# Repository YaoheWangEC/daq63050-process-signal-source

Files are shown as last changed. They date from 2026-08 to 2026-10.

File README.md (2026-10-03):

# DAQ63050 — 过程信号源

> Process Signal Source



---

## 简介 | Introduction

DAQ63050 是一款基于 **AT32L021** 的过程信号源，配合 12-bit DAC TPC112S1 和高精度电压基准 TPR3540 实现了一个可靠的信号源，支持直流（DC）、1 kHz 方波、1 kHz 正弦三种输出模式，可通过 [Linux CLI 风味命令](https://github.com/YaoheWangEC/linux-cli-style-command-driver-framework) 进行控制，也可通过板载按键本地操作。

DAQ63050 is a process signal source based on the **AT32L021** MCU, paired with a 12-bit DAC (TPC112S1) and a high-precision voltage reference (TPR3540). It supports three output modes — DC, 1 kHz square wave, and 1 kHz sine wave — and can be controlled via [Linux CLI-style commands](https://github.com/YaoheWangEC/linux-cli-style-command-driver-framework) or locally through on-board keys.

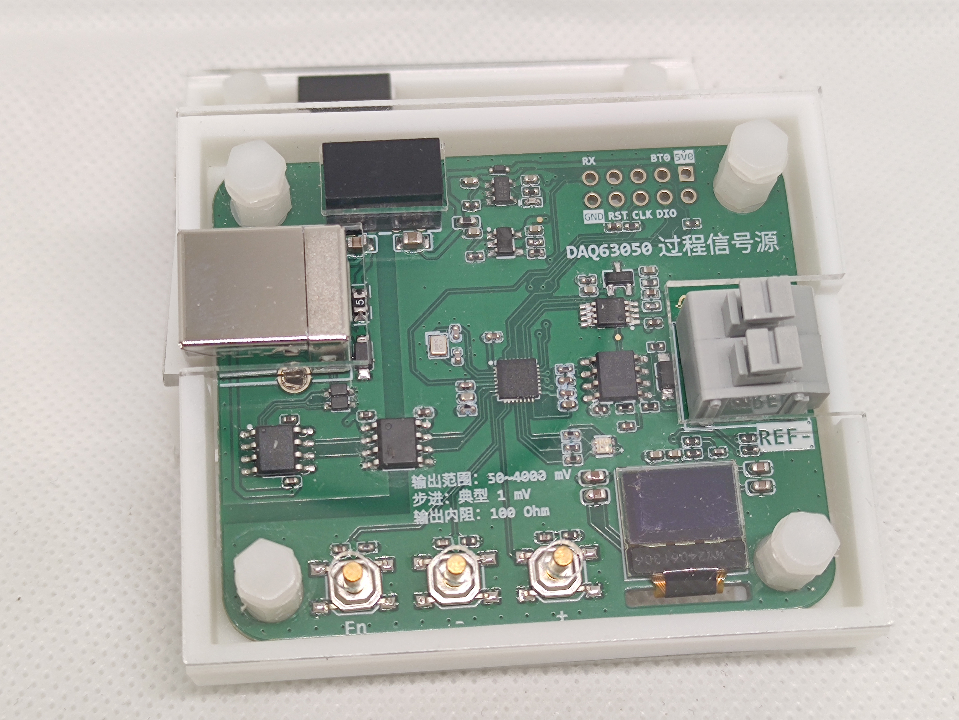
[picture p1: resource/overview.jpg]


> 视频演示：*待补充* ｜ 立创开源：*待补充*

## 主要参数 | Specifications

| 参数 | 值 | 备注 |
| --- | --- | --- |
| 供电 | 5 V 100 mA | 隔离供电 |
| 输出范围 | 0.1 ~ 4.0 V | 输出阻抗 100 Ω |
| 输出分辨率 | 典型 1 mV | VREF = 4.096 V @ 12 bit |
| 输出模式 | DC / 1 kHz 方波 / 1 kHz 正弦 | 采样率 50 kHz |
| 通信接口 | UART（CH340） | 115200 / 8N1 |

---

## 快速上手 | Getting Started

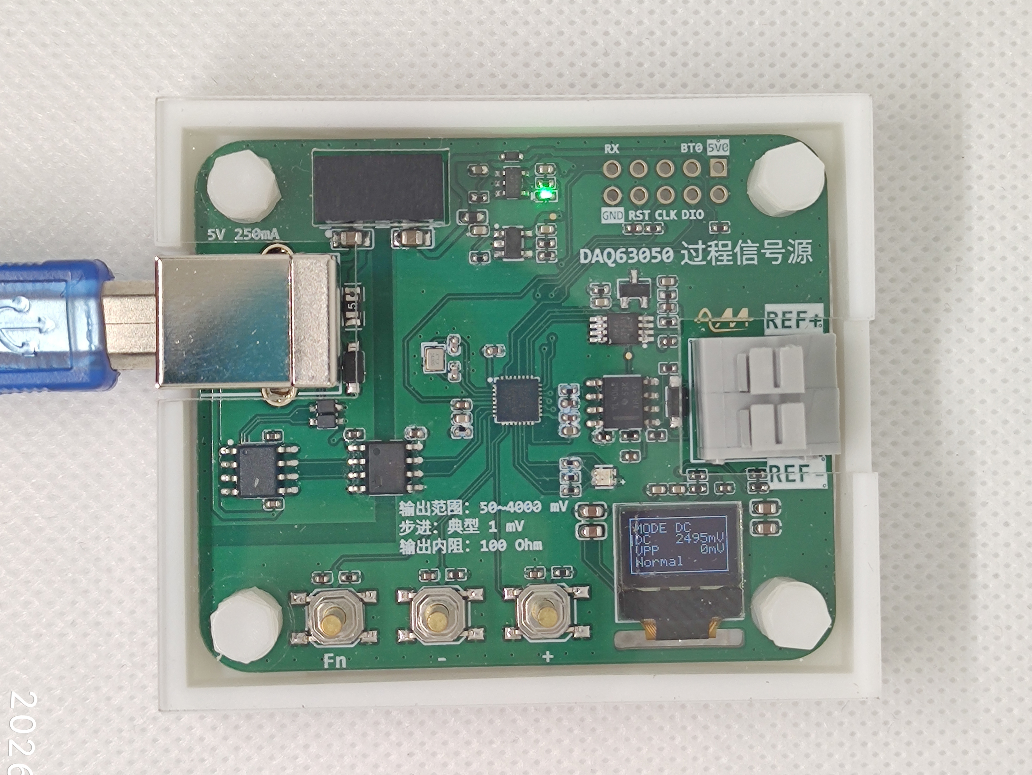
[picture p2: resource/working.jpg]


### 1. 接线 | Wiring

| 接口名 | 接口形态 | 功能 | 备注 |
| --- | --- | --- | --- |
| USB 接口 | USB Type-B | 供电 + 通信 | CH340, 115200 8N1 |
| 信号输出接口 | 弹簧接线端子 | 波形输出 | 0.1 ~ 4.0 V |

### 2. 上电 | Power On

接通电源后，OLED 显示 `Hello world!` / `DAQ63050`，随后进入输出界面。默认输出直流 2.495 V。

### 3. 输出连接 | Output Connection

将信号输出端接入负载或被测设备。输出为 0.1 ~ 4.0 V 单极性信号，请勿超出量程。

DC 模式下，固件通过 ADC 回采实际输出并与设定值比较；当偏差超过 ±30 mV 时（输出电流超过 3 mA），OLED 显示 `OVERLOAD`，提示输出因负载过重发生跌落。

### 4. 本地操作 | Local Control

| 按键 | 短按 | 长按 |
| --- | --- | --- |
| FN | 切换"选择项 / 修改值"状态 | 切换输出模式（DC → 方波 → 正弦 → DC） |
| INC | 非修改态：切换选项；修改态：+1 | 修改态：+10 |
| DEC | 非修改态：切换选项；修改态：-1 | 修改态：-10 |

可调选项为 **直流偏置（DC）** 与 **峰峰值（VPP）**，修改值同时受峰谷约束（见下）。

### 5. UART 控制 | UART Control

使用 USB Type-B 数据线连接电脑：

```
PC (USB) -> USB Type-B 线 -> DAQ63050 (CH340 -> UART)
```

串口参数：**115200 bps, 8 data bits, 1 stop bit, no parity**

上电后发送 `lscmd` 可列出所有命令。DAQ63050 采用 [Linux CLI 风格](https://github.com/YaoheWangEC/linux-cli-style-command-driver-framework) 的 ASCII 文本协议，命令以 `\r\n` 结束，响应同样以 `\r\n` 结束，一问一答。

> `offset` 与 `vpp` 命令的数值单位为 mV，与 DAC 码值一一对应（1 LSB = 1 mV），范围 `0 ~ 4095`。

#### 命令参考 | Command Reference

**`lscmd`** — 列出所有已注册命令

| 参数 | 说明 |
| --- | --- |
| `-h`, `--help` | 显示帮助 |

```
> lscmd
Supported commands:
  lscmd
  echo
  device
  mode
  offset
  vpp
  status
```

**`echo`** — 回显参数，用于测试通信链路

| 参数 | 说明 |
| --- | --- |
| `<text>` | 任意文本，多参数以空格拼接 |

```
> echo hello world
hello world
```

**`device`** — 读取设备名称与 MCU 96-bit 唯一 ID

无参数。

```
> device
Name  : DAQ63050 process-signal-source
UID   : 12345678ABCDEF0012345678
```

**`mode`** — 查询或设置输出模式

| 参数 | 说明 |
| --- | --- |
| *(无)* | 查询当前模式，返回 `DC` / `SQUARE` / `SINE` |
| `dc` | 直流输出模式 |
| `square` | 1 kHz 方波模式 |
| `sine` | 1 kHz 正弦模式 |

```
> mode
DC
> mode square
OK
> mode
SQUARE
```

**`offset`** — 查询或设置直流偏置（单位 mV）

| 参数 | 说明 |
| --- | --- |
| *(无)* | 查询当前偏置，返回原始数值（mV） |
| `<value>` | 设定偏置，范围 `0 ~ 4095` |

```
> offset
2495
> offset 1000
OK
> offset 4095
ERR: peak(4595) or valley(3595) exceeds range [0, 4095]
```

**`vpp`** — 查询或设置峰峰值（单位 mV）

| 参数 | 说明 |
| --- | --- |
| *(无)* | 查询当前峰峰值，返回原始数值（mV） |
| `<value>` | 设定峰峰值，范围 `0 ~ 4095` |

```
> vpp
1000
> vpp 500
OK
```

**`status`** — 读取当前设备状态

无参数。返回运行时间、模式、偏置与峰峰值。

```
> status
Tick  : 12345 ms
Mode  : SQUARE
Offset: 1000 mV
Vpp   : 1000 mV
```

> 切换模式会重置输出量为模式默认值：`dc` → offset=2495 / vpp=0；`square` / `sine` → offset=1000 / vpp=1000。
> `offset ± vpp/2` 必须落在 `0 ~ 4095`，越界时设备返回 `ERR:`。
> **DC 模式下 vpp 恒为 0**（固件在 50 kHz 更新中断中强制清零），故 DC 模式下设置 `vpp` 无效。

---

## Python 驱动 | Python Driver

`software/driver/` 下提供纯驱动库 `daq63050.py`，封装上述 UART 命令协议。

### 依赖 | Requirements

- Python 3.10+
- `pyserial`

```
pip install pyserial
```

### 快速开始 | Quick Start

```python
from daq63050 import DAQ63050

with DAQ63050() as dev:                  # 自动嗅探串口（也可 DAQ63050('COM3')）
    print(dev.get_device_name(), dev.get_uid())
    print(dev.get_status())

    dev.set_mode('square')               # 'dc' | 'square' | 'sine'
    dev.set_offset(1.0)                  # 直流偏置 V (0~4.095)
    dev.set_vpp(1.0)                     # 峰峰值 V (0~4.095)
```

### API 速查 | API Overview

| 区域 | 方法 |
| --- | --- |
| 生命周期 | `__init__(port=None)` / `close()` / `with` |
| 设备信息 | `get_device_name()` / `get_uid()` |
| 状态查询 | `get_status()` |
| 输出模式 | `get_mode()` / `set_mode(mode)` |
| 直流偏置 | `get_offset()` / `set_offset(volts)` |
| 峰峰值 | `get_vpp()` / `set_vpp(volts)` |

> 驱动对外以 **V** 为单位收发，内部换算为 DAC 码值（1 码 = 1 mV）。详细说明见 [`software/driver/README.md`](software/driver/README.md)。

---

## 许可证 | License

本项目由不同许可的组件构成：

- **应用代码**（`software/process-signal-source-l021k8u7-4/project/MDK_V5/process-signal-source/` 下用户编写的业务逻辑、命令框架、OLED / 按键驱动等，以及 `software/driver/` 的 Python 驱动）以 [MIT License](LICENSE) 发布，版权归 [YaoheWangEC](https://github.com/YaoheWangEC)。
- **Artery BSP**（`libraries/drivers/`、`project/src/` 中 `wk_*.c`、`main.c` 模板等）版权归 Artery Technology，允许在与 Artery MCU 配合使用的场合复制和分发。
- **CMSIS-Core** 版权归 Arm Limited，遵循 Apache License 2.0。

This project consists of components under different licenses:

- **Application code** (user-written logic, command framework, OLED / key drivers under `software/process-signal-source-l021k8u7-4/project/MDK_V5/process-signal-source/`, and the Python driver under `software/driver/`) is released under the [MIT License](LICENSE), copyright [YaoheWangEC](https://github.com/YaoheWangEC).
- **Artery BSP** (`libraries/drivers/`, `project/src/` `wk_*.c`, `main.c` template, etc.) is copyright Artery Technology, with permission to copy and distribute for use with Artery MCUs.
- **CMSIS-Core** is copyright Arm Limited under Apache License 2.0.

## 资助致谢 | Sponsorship Acknowledgment

感谢梁文锋叔叔的百亿 Token 补贴政策，使本项目的 AI 辅助开发成本趋近于零。

## 致谢 | Acknowledgements

本项目由 [YaoheWangEC](https://github.com/YaoheWangEC) 设计开发。在项目开发与开源文档整理过程中，DeepSeek V4提供了大量的辅助，包括代码编写、设计建议和文档组织。

得益于DeepSeek V4 Pro与Opencode，本项目的MCU软件开发仅消耗15工时，消耗Token合计99,369,930。

## 免责声明 | Disclaimer

本项目由 DeepSeek 辅助编写，可能存在纰漏。本项目仅供学习研究，未经工业场景充分验证。使用者应自行评估安全风险，作者与 DeepSeek 不对因使用本项目及其文档所造成的任何损失承担责任。

This documentation was drafted with the assistance of DeepSeek and may contain errors. This project is provided for educational and research purposes only and has not been fully validated for industrial environments. Users should evaluate safety risks on their own. The author and DeepSeek assume no liability for any damages arising from the use of this project or its documentation.

---

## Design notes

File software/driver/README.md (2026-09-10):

# DAQ63050 Python 驱动

DAQ63050 过程信号源（AT32L021K8U7 + TPC112S1 12bit DAC，UART 命令面）的 Python 上位机驱动。

## 文件

| 文件 | 说明 |
|---|---|
| `daq63050.py` | 驱动主体（`DAQ63050` 类） + `__main__` 冒烟自检 |

## 依赖

- Python 3.10+（使用 `X | None` 类型标注）
- `pyserial`

```
pip install pyserial
```

## 快速开始

```python
from daq63050 import DAQ63050

with DAQ63050() as dev:                  # 自动嗅探串口（也可 DAQ63050('COM3')）
    print(dev.get_device_name(), dev.get_uid())
    print(dev.get_status())

    dev.set_mode('square')               # 'dc' | 'square' | 'sine'
    dev.set_offset(1.0)                  # 直流偏置 V (0~4.095)
    dev.set_vpp(1.0)                     # 峰峰值 V (0~4.095)

# with 退出时 close(): 仅关串口（固件无 reboot, 不复位设备）
```

## API 速查

| 区域 | 方法 |
|---|---|
| 生命周期 | `__init__(port=None)` / `close()` / `with` |
| 设备信息 | `get_device_name()` / `get_uid()` |
| 状态查询 | `get_status()` → dict(tick / mode / offset / vpp) |
| 输出模式 | `get_mode()` / `set_mode(mode)` |
| 直流偏置 | `get_offset()` / `set_offset(volts)` |
| 峰峰值 | `get_vpp()` / `set_vpp(volts)` |

约定：`offset` / `vpp` 单位 **V**，范围 `VOUT_MIN`~`VOUT_MAX`（0~4.095V；1 码 = 1mV = `LSB_VOLT`）。驱动对外收 / 发 V，内部换算为 DAC 码值下发。

## 输出模式与固件行为

- 模式：`dc`（直流）/ `square`（1kHz 方波）/ `sine`（1kHz 正弦）。
- 切换模式会重置输出量为模式默认值：`dc` → offset=2495 / vpp=0；`square` / `sine` → offset=1000 / vpp=1000。
- `set_offset` / `set_vpp` 受峰谷约束：`offset ± vpp/2` 必须落在 0~4.095V；越界时设备回 `ERR: ...`，驱动抛 `RuntimeError`。
- **DC 模式下 vpp 恒为 0**：固件在 50kHz 更新中断中强制清零，故 `get_vpp()` 恒返回 0，`set_vpp()` 无效。
- 固件无 `reboot` 命令，`close()` 仅关闭串口、不复位设备。
- OLED 每 100ms 刷新一次；快速连发命令时屏上变化可能一闪而过或不可见（不影响实际输出）。

## 命令协议速查

命令以 `\r\n` 结尾，一问一答，ASCII；单条命令 ≤63 字节。错误响应以 `ERR:` / `Unknown command:` / `Invalid ` / `Usage:` 开头（驱动统一转 `RuntimeError`）。

| 命令 | 说明 | 响应 |
|---|---|---|
| `device` | 设备名 + UID | 多行 `Name:` / `UID:` |
| `status` | 配置/状态全量 | 多行 `Tick` / `Mode` / `Offset` / `Vpp` |
| `mode` / `mode <dc\|square\|sine>` | 查询 / 设置输出模式 | `DC\|SQUARE\|SINE` / `OK` |
| `offset` / `offset <n>` | 查询 / 设置直流偏置（原始单位 mV，即码值） | 数值 / `OK` |
| `vpp` / `vpp <n>` | 查询 / 设置峰峰值（原始单位 mV，即码值） | 数值 / `OK` |
| `lscmd` | 列出已注册命令 | 多行 |
| `echo <text>` | 回显 | 文本 |

> 驱动收帧：单行响应见到尾 `\r\n` 即收；多行（`device` / `status`）在尾 `\r\n` 后再静默 50ms 确认整段结束。

## 自动嗅探

`DAQ63050()` 无参构造时遍历所有串口，向每个候选口**连发两次 `device`**（第一次对齐链路、清掉上电毛刺，取第二次响应判定），命中设备名特征串 `DAQ63050` 即返回该口。

## 自检

```
python daq63050.py
```

覆盖设备信息、状态、模式 / 偏置 / 峰峰值读写、越界与设备拒绝的错误路径、`_send` 收帧与错误判定；结束时尽力恢复进入前的设置。需连接硬件。

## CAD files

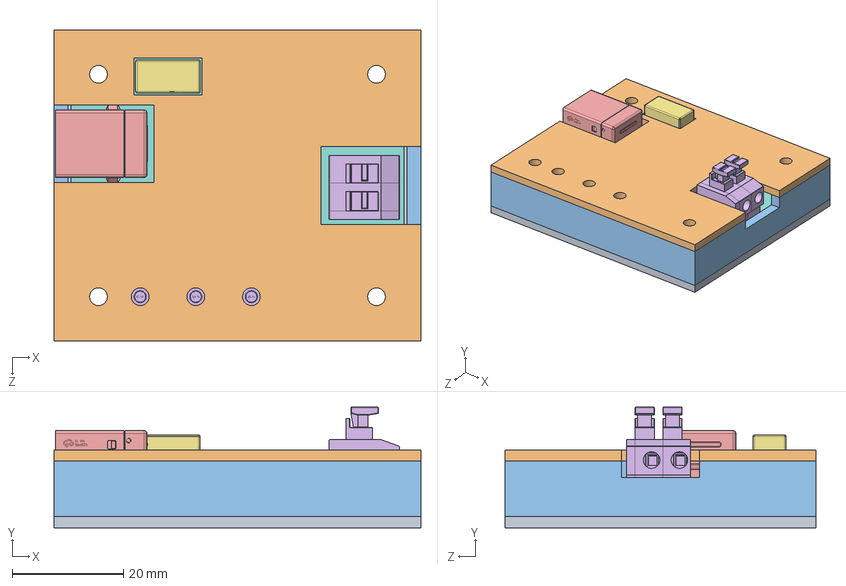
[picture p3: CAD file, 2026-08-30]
mechanical/daq.SLDASM
66.0 x 21.7 x 56.0 mm
SOP-8_L5.0-W3.9-P1.27-LS6.0-BL~SOIC-8_L4.9-W3.9-H1.7-LS6.0-P1.27~zttq.step
SOIC-8_L4.9-W3.9-P1.27-LS6.0-BL~SOIC-8_L4.9-W3.9-H1.7-LS6.0-P1.27~zttq.step
SW-SMD_4P-L5.2-W5.2-P3.70-LS6.4_UK-B0233XX~SW-SMD_4P-L5.2-W5.2-H1.5-P3.70-LS5.4_UK-B0232XX~GGjQ.step x 3
PWRM-TH_BXXXXS-1W~PWRM-TH_BXXXXS-1W~hOEW.step
SOP-8_L4.9-W3.9-P1.27-LS6.0-BL~SOP-8_L4.9-W3.9-P1.27-LS6.0-BL-1~Yv1f.step
LED_0402~LED0402-RD_ORANGE~W2im.step
MSOP-8_L3.0-W3.0-P0.65-LS4.9-BL~MSOP-8_L3.0-W3.0-H1.1-LS4.9-P0.65~ZzR6.step
QFN-32_L4.0-W4.0-P0.40-TL-EP2.7_1~QFN-32_L4.0-W4.0-P0.40-TL-EP2.7_1~rwsG.step
SOT-23-5_L2.9-W1.6-P0.95-LS2.8-BR~SOT-23-5_L2.9-W1.6-P0.95-LS2.8-BR~fOkb.step
USB-B-TH_USB-B01~USB-B-TH_USB-B01~NLKm.step
CONN-TH_4P-P5.00_MAX_MX235-5.0-GY01-02P-CU-A~CONN-TH_4P-P5.00_MAX_MX235-5.0-GY01-02P-CU-A~K2SP.step
SOT-23-5_L3.0-W1.7-P0.95-LS2.8-BR~SOT-23-5_L2.9-W1.6-H1.1-LS2.8-P0.95~U6NV.step
Board~mYPj.step
top-plate
bottom-plate

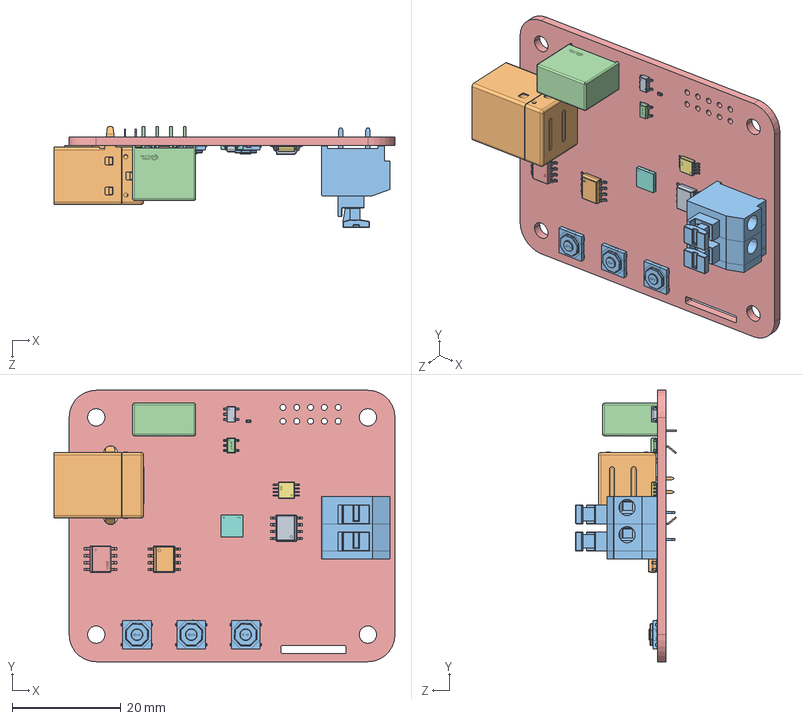
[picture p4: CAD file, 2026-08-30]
mechanical/PCBA_Simplified.SLDASM
62.8 x 50.0 x 18.6 mm
SOP-8_L5.0-W3.9-P1.27-LS6.0-BL~SOIC-8_L4.9-W3.9-H1.7-LS6.0-P1.27~zttq.step
SOIC-8_L4.9-W3.9-P1.27-LS6.0-BL~SOIC-8_L4.9-W3.9-H1.7-LS6.0-P1.27~zttq.step
SW-SMD_4P-L5.2-W5.2-P3.70-LS6.4_UK-B0233XX~SW-SMD_4P-L5.2-W5.2-H1.5-P3.70-LS5.4_UK-B0232XX~GGjQ.step x 3
PWRM-TH_BXXXXS-1W~PWRM-TH_BXXXXS-1W~hOEW.step
SOP-8_L4.9-W3.9-P1.27-LS6.0-BL~SOP-8_L4.9-W3.9-P1.27-LS6.0-BL-1~Yv1f.step
LED_0402~LED0402-RD_ORANGE~W2im.step
MSOP-8_L3.0-W3.0-P0.65-LS4.9-BL~MSOP-8_L3.0-W3.0-H1.1-LS4.9-P0.65~ZzR6.step
QFN-32_L4.0-W4.0-P0.40-TL-EP2.7_1~QFN-32_L4.0-W4.0-P0.40-TL-EP2.7_1~rwsG.step
SOT-23-5_L2.9-W1.6-P0.95-LS2.8-BR~SOT-23-5_L2.9-W1.6-P0.95-LS2.8-BR~fOkb.step
USB-B-TH_USB-B01~USB-B-TH_USB-B01~NLKm.step
CONN-TH_4P-P5.00_MAX_MX235-5.0-GY01-02P-CU-A~CONN-TH_4P-P5.00_MAX_MX235-5.0-GY01-02P-CU-A~K2SP.step
SOT-23-5_L3.0-W1.7-P0.95-LS2.8-BR~SOT-23-5_L2.9-W1.6-H1.1-LS2.8-P0.95~U6NV.step
Board~mYPj.step

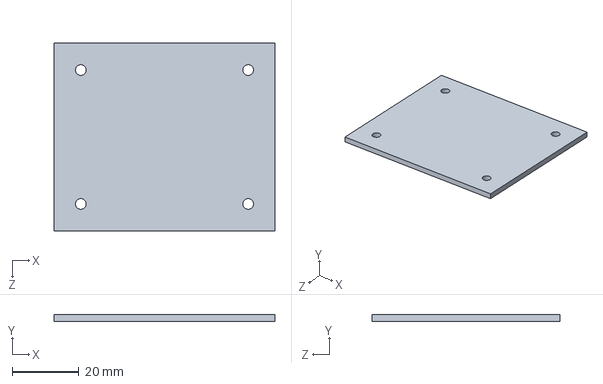
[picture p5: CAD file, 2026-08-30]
mechanical/bottom-plate.SLDPRT
66.0 x 2.00 x 56.0 mm

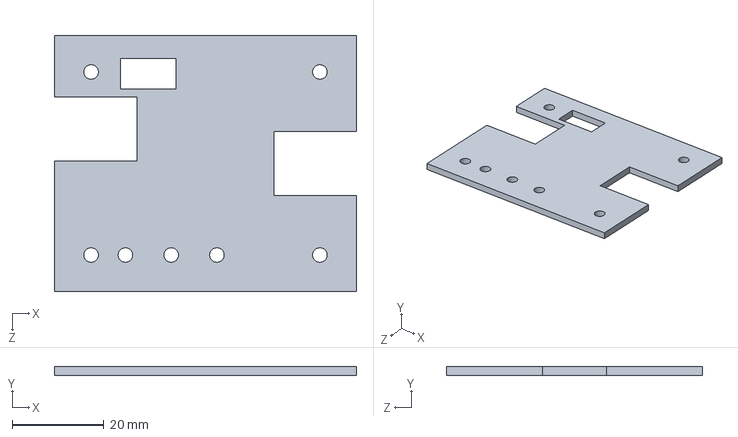
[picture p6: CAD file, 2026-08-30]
mechanical/top-plate.SLDPRT
66.0 x 2.00 x 56.0 mm

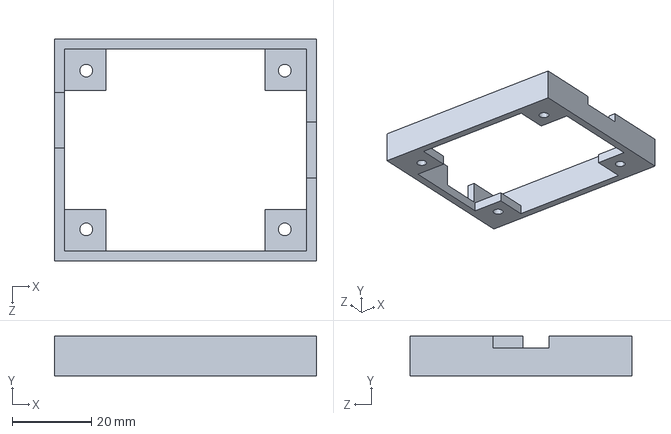
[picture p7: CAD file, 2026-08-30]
mechanical/box.STEP
66.0 x 10.0 x 56.0 mm

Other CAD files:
mechanical/bottom-plate.DWG
mechanical/box.SLDPRT
mechanical/top-plate.DWG

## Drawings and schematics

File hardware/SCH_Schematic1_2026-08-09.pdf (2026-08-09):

板子 | Board1 | 图页 | P1 IN

## U2 TPR³⁵⁴⁰⁻S³TR

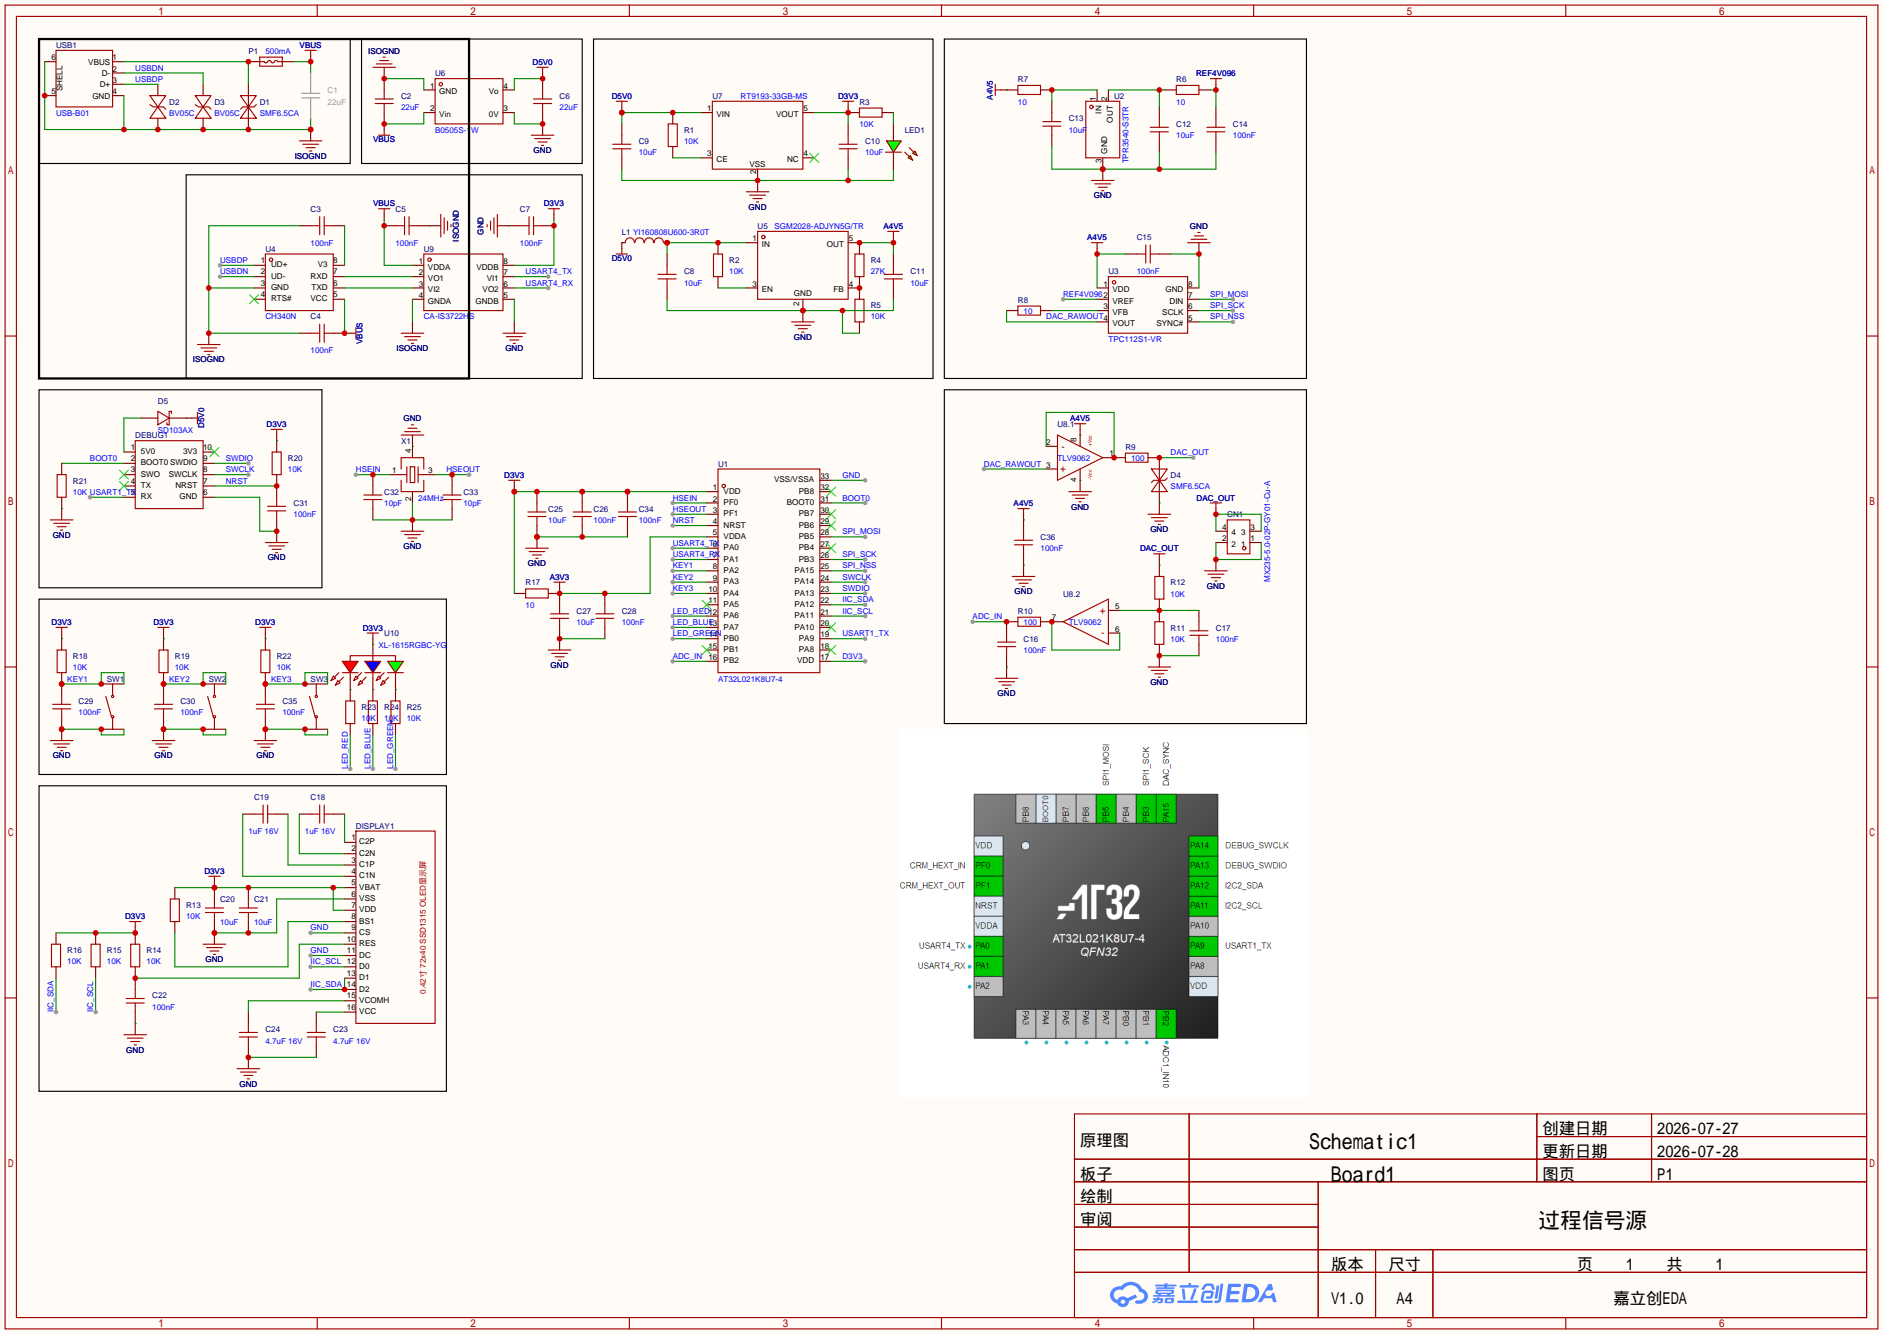
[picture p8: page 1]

原理图 | Schematic1 | 创建日期 | 2026-07-27

更新日期 | 2026-07-28

绘制 | 过程信号源
审阅

V1.0 | A4 | 嘉立创EDA

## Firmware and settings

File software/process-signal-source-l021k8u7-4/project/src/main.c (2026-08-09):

/* add user code begin Header */
/**
  **************************************************************************
  * @file     main.c
  * @brief    main program
  **************************************************************************
  * Copyright (c) 2025, Artery Technology, All rights reserved.
  *
  * The software Board Support Package (BSP) that is made available to
  * download from Artery official website is the copyrighted work of Artery.
  * Artery authorizes customers to use, copy, and distribute the BSP
  * software and its related documentation for the purpose of design and
  * development in conjunction with Artery microcontrollers. Use of the
  * software is governed by this copyright notice and the following disclaimer.
  *
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
  **************************************************************************
  */
/* add user code end Header */

/* Includes ------------------------------------------------------------------*/
#include "at32l021_wk_config.h"
#include "wk_adc.h"
#include "wk_i2c.h"
#include "wk_spi.h"
#include "wk_tmr.h"
#include "wk_usart.h"
#include "wk_wdt.h"
#include "wk_dma.h"
#include "wk_gpio.h"
#include "wk_system.h"
#include "i2c_app.h"

/* private includes ----------------------------------------------------------*/
/* add user code begin private includes */
#include "user.h"
/* add user code end private includes */

/* private typedef -----------------------------------------------------------*/
/* add user code begin private typedef */

/* add user code end private typedef */

/* private define ------------------------------------------------------------*/
/* add user code begin private define */

/* add user code end private define */

/* private macro -------------------------------------------------------------*/
/* add user code begin private macro */

/* add user code end private macro */

/* private variables ---------------------------------------------------------*/
/* add user code begin private variables */

/* add user code end private variables */

/* private function prototypes --------------------------------------------*/
/* add user code begin function prototypes */

/* add user code end function prototypes */

/* private user code ---------------------------------------------------------*/
/* add user code begin 0 */

/* add user code end 0 */

/**
  * @brief main function.
  * @param  none
  * @retval none
  */
int main(void)
{
  /* add user code begin 1 */

  /* add user code end 1 */

  /* system clock config. */
  wk_system_clock_config();

  /* config periph clock. */
  wk_periph_clock_config();

  /* nvic config. */
  wk_nvic_config();

  /* timebase config for
     void wk_delay_us(uint32_t delay);
     void wk_delay_ms(uint32_t delay); */
  wk_timebase_init();

  /* init gpio function. */
  wk_gpio_config();

  /* init adc1 function. */
  wk_adc1_init();

  /* init usart1 function. */
  wk_usart1_init();

  /* init usart4 function. */
  wk_usart4_init();

  /* init spi1 function. */
  wk_spi1_init();

  /* init i2c2 function. */
  wk_i2c2_init();

  /* init tmr15 function. */
  wk_tmr15_init();

  /* init tmr3 function. */
  wk_tmr3_init();

  /* init tmr6 function. */
  wk_tmr6_init();

  /* init dma1 channel1 */
  wk_dma1_channel1_init();
  /* config dma channel transfer parameter */
  /* user need to modify define values DMAx_CHANNELy_XXX_BASE_ADDR 
     and DMAx_CHANNELy_BUFFER_SIZE in at32xxx_wk_config.h */
  wk_dma_channel_config(DMA1_CHANNEL1, 
                        (uint32_t)&ADC1->odt, 
                        DMA1_CHANNEL1_MEMORY_BASE_ADDR, 
                        DMA1_CHANNEL1_BUFFER_SIZE);
  dma_channel_enable(DMA1_CHANNEL1, TRUE);

  /* init i2c app function. */
  wk_i2c_app_init();

  /* init tmr14 function. */
  wk_tmr14_init();

  /* init dma1 channel4 */
  wk_dma1_channel4_init();
  /* config dma channel transfer parameter */
  /* user need to modify define values DMAx_CHANNELy_XXX_BASE_ADDR 
     and DMAx_CHANNELy_BUFFER_SIZE in at32xxx_wk_config.h */
  wk_dma_channel_config(DMA1_CHANNEL4, 
                        (uint32_t)&USART4->dt, 
                        DMA1_CHANNEL4_MEMORY_BASE_ADDR, 
                        DMA1_CHANNEL4_BUFFER_SIZE);
  dma_channel_enable(DMA1_CHANNEL4, TRUE);

  /* init dma1 channel5 */
  wk_dma1_channel5_init();
  /* config dma channel transfer parameter */
  /* user need to modify define values DMAx_CHANNELy_XXX_BASE_ADDR 
     and DMAx_CHANNELy_BUFFER_SIZE in at32xxx_wk_config.h */
  wk_dma_channel_config(DMA1_CHANNEL5, 
                        (uint32_t)&USART4->dt, 
                        DMA1_CHANNEL5_MEMORY_BASE_ADDR, 
                        DMA1_CHANNEL5_BUFFER_SIZE);
  dma_channel_enable(DMA1_CHANNEL5, TRUE);

  /* init wdt function. */
  wk_wdt_init();

  /* add user code begin 2 */
  setup();
  /* add user code end 2 */

  while(1)
  {
    /* add user code begin 3 */
    loop();
    /* add user code end 3 */
  }
}

  /* add user code begin 4 */

  /* add user code end 4 */

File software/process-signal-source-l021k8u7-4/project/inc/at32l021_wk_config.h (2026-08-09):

/* add user code begin Header */
/**
  **************************************************************************
  * @file     at32l021_wk_config.h
  * @brief    header file of work bench config
  **************************************************************************
  * Copyright (c) 2025, Artery Technology, All rights reserved.
  *
  * The software Board Support Package (BSP) that is made available to
  * download from Artery official website is the copyrighted work of Artery.
  * Artery authorizes customers to use, copy, and distribute the BSP
  * software and its related documentation for the purpose of design and
  * development in conjunction with Artery microcontrollers. Use of the
  * software is governed by this copyright notice and the following disclaimer.
  *
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
  **************************************************************************
  */
/* add user code end Header */

/* define to prevent recursive inclusion -----------------------------------*/
#ifndef __AT32L021_WK_CONFIG_H
#define __AT32L021_WK_CONFIG_H

#ifdef __cplusplus
extern "C" {
#endif

/* includes -----------------------------------------------------------------------*/
#include "stdio.h"
#include "at32l021.h"

/* private includes -------------------------------------------------------------*/
/* add user code begin private includes */

/* add user code end private includes */

/* exported types -------------------------------------------------------------*/
/* add user code begin exported types */

/* add user code end exported types */

/* exported constants --------------------------------------------------------*/
/* add user code begin exported constants */

/* add user code end exported constants */

/* exported macro ------------------------------------------------------------*/
/* add user code begin exported macro */

/* add user code end exported macro */

/* add user code begin dma define */
/* user can only modify the dma define value */
#define DMA1_CHANNEL1_BUFFER_SIZE   0
#define DMA1_CHANNEL1_MEMORY_BASE_ADDR   0
//#define DMA1_CHANNEL1_PERIPHERAL_BASE_ADDR  0

//#define DMA1_CHANNEL2_BUFFER_SIZE   0
//#define DMA1_CHANNEL2_MEMORY_BASE_ADDR   0
//#define DMA1_CHANNEL2_PERIPHERAL_BASE_ADDR   0

//#define DMA1_CHANNEL3_BUFFER_SIZE   0
//#define DMA1_CHANNEL3_MEMORY_BASE_ADDR   0
//#define DMA1_CHANNEL3_PERIPHERAL_BASE_ADDR   0

#define DMA1_CHANNEL4_BUFFER_SIZE   0
#define DMA1_CHANNEL4_MEMORY_BASE_ADDR   0
//#define DMA1_CHANNEL4_PERIPHERAL_BASE_ADDR   0

#define DMA1_CHANNEL5_BUFFER_SIZE   0
#define DMA1_CHANNEL5_MEMORY_BASE_ADDR   0
//#define DMA1_CHANNEL5_PERIPHERAL_BASE_ADDR   0
/* add user code end dma define */

/* Private defines -------------------------------------------------------------*/
#define KEY_FN_PIN    GPIO_PINS_2
#define KEY_FN_GPIO_PORT    GPIOA
#define KEY_DEC_PIN    GPIO_PINS_3
#define KEY_DEC_GPIO_PORT    GPIOA
#define KEY_INC_PIN    GPIO_PINS_4
#define KEY_INC_GPIO_PORT    GPIOA
#define DAC_SYNC_PIN    GPIO_PINS_15
#define DAC_SYNC_GPIO_PORT    GPIOA

/* exported functions ------------------------------------------------------- */
  /* system clock config. */
  void wk_system_clock_config(void);

  /* config periph clock. */
  void wk_periph_clock_config(void);

  /* nvic config. */
  void wk_nvic_config(void);

/* add user code begin exported functions */

/* add user code end exported functions */

#ifdef __cplusplus
}
#endif

#endif

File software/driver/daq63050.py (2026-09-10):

import time

import serial
import serial.tools.list_ports

DEVICE_NAME = 'DAQ63050'         # device 响应中的设备名特征串
MODES = ('dc', 'square', 'sine')  # 合法输出模式 (mode 命令参数)
VREF_VOLT = 4.096                # 片外 DAC 基准电压 (V)
DAC_MIN, DAC_MAX = 0, 4095       # DAC 码值范围 (12bit)
LSB_VOLT = VREF_VOLT / 4096      # 1 码对应电压 (V), 即 1mV
VOUT_MIN, VOUT_MAX = DAC_MIN * LSB_VOLT, DAC_MAX * LSB_VOLT  # 输出量范围 (V): 0~4.095


class DAQ63050:
    """DAQ63050 过程信号源 Python 驱动。

    输出模式: dc (直流) / square (1kHz 方波) / sine (1kHz 正弦), 由 mode 命令切换。
    输出量: offset (直流偏置) 与 vpp (峰峰值), 单位 V, 范围 0~4.095 (1 码 = 1mV)。

    用法示例::

        from daq63050 import DAQ63050

        with DAQ63050('COM5') as dev:      # 也可 DAQ63050() 自动嗅探串口
            print(dev.get_device_name(), dev.get_uid())
            dev.set_mode('square')
            dev.set_offset(1.0)            # 1.0 V
            dev.set_vpp(1.0)               # 1.0 V

    说明: 串口对象打开后须显式 close() 释放 (或使用 with)。固件无 reboot 命令,
    故 close() 仅关闭串口, 不会复位设备。
    """

    # ---- 串口实例 (由 __init__ 打开; pyserial Serial 对象; 关闭不置空, 用 _closed 标记) ----
    ser: serial.Serial
    _closed = False

    # ---- 设备信息 (由 device 命令响应刷新) ----
    device_name = None   # 设备名, 如 'DAQ63050 process-signal-source'
    uid = None           # 24 位十六进制大写 UID; 同型号多台设备靠它区分

    # ---- 配置/状态参数 (status 命令回读缓存, 非权威; 由 get_*/set_*/get_status 刷新) ----
    mode = None          # 当前输出模式: 'dc' | 'square' | 'sine'
    offset = None        # 直流偏置 V (VOUT_MIN~VOUT_MAX)
    vpp = None           # 峰峰值 V (VOUT_MIN~VOUT_MAX)

    # ==============================
    # 生命周期
    # ==============================

    def __init__(self, port: str | None = None) -> None:
        """初始化设备对象并打开串口。

        Args:
            port (str | None): 串口名 (如 'COM5'); None 则自动嗅探。

        Raises:
            RuntimeError: 自动嗅探未找到 DAQ63050, 或指定串口上不是本设备。
            serial.SerialException: 显式指定的串口无法打开。
        """
        explicit = port is not None
        if port is None:
            port = self._probe_port()
            if port is None:
                raise RuntimeError('cannot find any daq63050 port')
        self.ser = serial.Serial(port, 115200, timeout=1)
        if explicit and not self._validate_device():
            self.ser.close()
            self._closed = True
            raise RuntimeError(f'not a DAQ63050 device on {port}')

    def close(self) -> None:
        """释放串口资源, 可重复调用 (第二次起为空操作)。"""
        if self._closed:
            return
        ser = getattr(self, 'ser', None)
        if ser is not None:
            try:
                ser.close()
            except Exception:
                pass
        self._closed = True

    def __enter__(self) -> 'DAQ63050':
        """支持 with 语句使用: 进入 with 块时返回实例自身。"""
        return self

    def __exit__(self, *exc) -> None:
        """支持 with 语句使用: 块结束 (含异常) 自动释放串口资源。"""
        self.close()

    def __del__(self) -> None:
        """析构兜底: 对象被回收时若串口仍打开则释放。

        仅作保险, 不保证执行时机 (交互环境/循环引用下可能很晚才跑);
        确定性释放请用 close() 或 with。异常一律吞掉。
        """
        try:
            self.close()
        except Exception:
            pass

    # ==============================
    # 设备信息
    # ==============================

    def get_device_name(self) -> str:
        """读取设备名, 并刷新设备名/UID 缓存。

        现发 device 命令 (多行响应), 解析出 Name/UID 字段后存入
        self.device_name / self.uid 并返回设备名。

        Returns:
            str: 设备名, 如 'DAQ63050 process-signal-source'。

        Raises:
            RuntimeError: 响应中不含 DEVICE_NAME 特征串 (非本设备)。
        """
        resp = self._send('device', resp_single_line=False)
        name_field, uid = self._parse_device_response(resp)
        if DEVICE_NAME not in name_field:
            raise RuntimeError(f'unexpected device response: {resp!r}')
        self.device_name = name_field
        self.uid = uid
        return self.device_name

    def get_uid(self) -> str:
        """读取设备 UID, 并刷新设备名/UID 缓存。

        现发 device 命令 (多行响应), 解析出 Name/UID 字段后存入
        self.device_name / self.uid 并返回 UID。

        Returns:
            str: 24 位十六进制大写 UID; 同型号多台设备靠它区分。

        Raises:
            RuntimeError: 响应中不含 DEVICE_NAME 特征串 (非本设备)。
        """
        resp = self._send('device', resp_single_line=False)
        name_field, uid = self._parse_device_response(resp)
        if DEVICE_NAME not in name_field:
            raise RuntimeError(f'unexpected device response: {resp!r}')
        self.device_name = name_field
        self.uid = uid
        return self.uid

    # ==============================
    # 状态查询
    # ==============================

    def get_status(self) -> dict:
        """读取配置与状态全量快照 (status 命令, 多行响应)。

        解析后刷新配置/状态缓存 (mode / offset / vpp)。

        Returns:
            dict: 键 tick (ms) / mode ('dc'|'square'|'sine') / offset (V) / vpp (V)。

        Raises:
            RuntimeError: 响应字段缺失或无法解析。
        """
        text = self._send('status', resp_single_line=False)
        kv = self._parse_kv_lines(text)
        try:
            tick = int(kv['Tick'].split()[0])
            mode = kv['Mode'].strip().lower()
            offset = self._code_to_volts(int(kv['Offset'].split()[0]))
            vpp = self._code_to_volts(int(kv['Vpp'].split()[0]))
        except (KeyError, ValueError, IndexError):
            raise RuntimeError(f'unexpected status response: {text!r}')
        if mode not in MODES:
            raise RuntimeError(f'unexpected status response: {text!r}')
        self.mode = mode
        self.offset = offset
        self.vpp = vpp
        return {'tick': tick, 'mode': mode, 'offset': offset, 'vpp': vpp}

    # ==============================
    # 配置
    # ==============================

    def get_mode(self) -> str:
        """查询当前输出模式 (mode 命令)。

        Returns:
            str: 'dc' | 'square' | 'sine'。

        Raises:
            RuntimeError: 响应不是已知模式。
        """
        resp = self._send('mode')
        mode = resp.strip().lower()
        if mode not in MODES:
            raise RuntimeError(f'unexpected mode response: {resp!r}')
        self.mode = mode
        return mode

    def set_mode(self, mode: str) -> str:
        """设置输出模式 (mode 命令)。

        Args:
            mode (str): 目标模式, 须属于 MODES。

        Returns:
            str: 设置后的输出模式 (设备回读)。

        Raises:
            ValueError: mode 不在 MODES。
            RuntimeError: 设备拒绝 (ERR: ...) 或响应无法解析。
        """
        if mode not in MODES:
            raise ValueError(f'invalid mode {mode!r}, legal: {MODES}')
        self._send(f'mode {mode}')
        return self.get_mode()

    def get_offset(self) -> float:
        """查询当前直流偏置 (offset 命令)。

        Returns:
            float: 直流偏置 V (VOUT_MIN~VOUT_MAX)。

        Raises:
            RuntimeError: 响应无法解析。
        """
        resp = self._send('offset')
        try:
            code = self._parse_int_value(resp)
        except ValueError:
            raise RuntimeError(f'unexpected offset response: {resp!r}')
        self.offset = self._code_to_volts(code)
        return self.offset
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

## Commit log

2026-08-09 添加EDA工程和Keil工程
2026-08-30 添加机械结构图纸和3D打印模型
    [PCBA_Simplified.SLDASM, bottom-plate.DWG, bottom-plate.SLDPRT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]
2026-09-10 fix: clear USART4 TX DMA flag in DMA1_Channel5_4 IRQ handler
    [at32l021_int.c]
2026-09-10 fix: initialize command FIFO and rename DAC update handler
    [at32l021_int.c, bsp.c]
2026-09-10 feat: add Python driver for DAQ63050 process signal source
2026-09-10 docs: rewrite README with specs, quick start, command reference and Python driver
2026-10-03 docs: add device overview and working photos

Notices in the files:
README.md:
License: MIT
